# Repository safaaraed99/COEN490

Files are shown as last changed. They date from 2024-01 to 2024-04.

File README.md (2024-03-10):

# COEN490 Hardware
This repository contains the PCB design files and AVR microcontroller firmware.

# Firmware contribution
First, install [Microchip Studio](https://www.microchip.com/en-us/tools-resources/develop/microchip-studio) (AKA Atmel Studio).

Next, create a new branch for the feature you want to add. Open up the solution under avr_firmware, make the modifications, commit and push to your branch. Then open up a PR and wait for a review before merging.

See `docs/main.md` for documentation links and programming guides.

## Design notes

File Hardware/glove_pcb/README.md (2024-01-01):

Hardware design for the project's PCB

1. Download [Kicad](https://www.kicad.org/) and open `glove_pcb.kicad_pro`
2. Modify schematic in `glove_pcb.kicad_sch`
3. Modify PCB layout in `glove_pcb.kicad_pcb`

TODO write more here!!

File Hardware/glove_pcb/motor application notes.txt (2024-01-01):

I_PROPI (uA) = (I_LS1 + I_LS2) (A) * A_IPROPI (uA/A)
    - I_PROPI = Current coming out of IPROPI pin
    - I_LSx = Value in low side MOSFETs of H-bridge
    - A_IPROPI = Current sensing gain (typically 1k uA/A)

V_IPROPI (V) = I_PROPI (uA) * R_IPROPI (Ohm)
    - V_IPROPI = Value measured in ADC, voltage across R_IPROPI
    - R_IPROPI = Resistance between IPROPI pin and ground

I_TRIP (A) * A_IPROPI (uA/A) = V_VREF (V) / R_IPROPI (Ohm)
    - I_TRIP = Max current allowed by current regulator
    - V_VREF = Voltage on VREF input pin (max 3.6V)
    - Note that RHS = I_PROPI
    - Disable current regulation without disabling current regulation by setting V_VREF and R_IPROPI s.t. I_TRIP is never reached

Calculations:
Use maximum recommended V_VREF value of 3.6 V (pin maxes out at 5V but this is recommended max for continuous operation)
Choose I_TRIP = 1A (motor rated for ~0.6A and stalls at ~1.7A)
R_IPROPI = 3.6 kOhm
Gives maximum V_IPROPI of 3.6 V

Alternative I_TRIP = 0.8A
R_IPROPI = 4.5 kOhm
V_IPROPI = 3.6V

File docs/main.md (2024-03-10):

# Hardware Programming Cookbook

## Introduction
This document contains information that will help with programming the ATMega328PB microprocessor used in the project hardware.

## ATMega328PB Pin Assignment and Peripherals
ATMega328PB pinout

* UART 0: Communication with Bluetooth module.
* UART 1: Debug serial communication. Shares pins with SPI 0.
* SPI 0: ISCP. Shares pins with UART 1.
* SPI 1: Communication with ADCs and IMU.
* I2C 0: Not used.
* I2C 1: Not used.
* Hardware timer 0: Both channels used for motor PWM control.
* Hardware timer 1: Both channels used for motor PWM control.
* Hardware timer 2: Channel B used for motor PWM control. Channel A unused.
* Hardware timer 3: Not used.
* Hardware timer 4: Not used.

| Pin identifier | Pin assignment |
| --- | --- |
| PB0 | Peripheral sleep/reset (GPIO) |
| PB1 | Timer/counter 1 output channel A (PWM) |
| PB2 | Timer/counter 1 output channel B (PWM) |
| PB3 | SPI 0 MISO; UART 1 TX |
| PB4 | SPI 0 MOSI; UART 1 RX |
| PB5 | SPI 0 SCK |
| PB6 | Motor 1 fault (GPIO interrupt) |
| PB7 | Motor 2 fault (GPIO interrupt) |
| PC0 | SPI 1 MISO |
| PC1 | SPI 1 SCK |
| PC2 | ADC 2 chip select (GPIO active-low) |
| PC3 | ADC 3 chip select (GPIO active-low) |
| PC4 | Motor phase control 2 (GPIO) |
| PC5 | IMU chip select (GPIO active-low) |
| PC6 | Reset input (GPIO active-low, external pull-up) |
| PD0 | UART 0 RX |
| PD1 | UART 0 TX |
| PD2 | Motor phase control 1 (GPIO) |
| PD3 | Timer/counter 2 output channel B (PWM) |
| PD4 | Motor 5 fault (GPIO interrupt) |
| PD5 | Timer/counter 0 output channel B (PWM) |
| PD6 | Timer/counter 0 output channel A (PWM) |
| PD7 | Motor phase control 3 (GPIO) |
| PE0 | Motor 3 fault (GPIO interrupt) |
| PE1 | Motor 4 fault (GPIO interrupt) |
| PE2 | ADC 1 chip select (GPIO active-low) |
| PE3 | SPI 1 MOSI |

### SPI pin names
* MOSI = Master Out Slave In
* MISO = Master In Slave Out
* SS/CS = Slave Select/Chip Select

All SPI devices share the same MOSI/MISO pins.
Each slave device has a unique CS pin.
CS pins are **ACTIVE-LOW**.
They must be kept high when idle, and should be pulled low by the master (our microcontroller) when we want to communicate with the slave.
Only one CS pin should be low at a time.

## ATMega328PB Programming Guide
[Datasheet](https://ww1.microchip.com/downloads/aemDocuments/documents/MCU08/ProductDocuments/DataSheets/40001906C.pdf)

## ADC Usage Guide
[Datasheet](https://ww1.microchip.com/downloads/en/DeviceDoc/21295d.pdf)

[Useful guide] (https://engineerworkshop.com/blog/interfacing-an-8-bit-microcontroller-with-a-10-bit-device-over-the-spi-protocol/)

## Motor Driver Usage Guide
[Datasheet](https://www.ti.com/lit/ds/symlink/drv8876.pdf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)

## IMU Usage Guide

## Bluetooth Usage Guide
[Datasheet](https://ww1.microchip.com/downloads/en/DeviceDoc/BM70-71-Bluetooth-Low-Energy-BLE-Module-Data-Sheet-DS60001372J.pdf)

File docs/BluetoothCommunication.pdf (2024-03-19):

Bluetooth Communication Protocol
1. Pick UUID Glove:
i. Online generator: 837ee2f0-d412-4af9-b847-c5ffd223640f
2. Control commands (from app to glove)
i. Used by the Android app to send commands to the glove, like starting an exercise or setting resistance.
3. Response commands (from glove to app)
i. Used by the glove to send data back to the app, like sensor readings.
ii. | We need sensor data + ACK.
iii. | Warnings:
i. To send warnings to the glove. The app will show a dialog about the
| warning type and the glove will be set to Stop exercise.
| ii. Glove send 2 bytes (1 byte for warning and the other for the type of
| warning)
| iii. 0x01: Motor Failure
| iv. 0x02: if needed we can add a second warning
v. 0x04: if needed we can add a third warning
4. Communication flow:
i. From Android to Glove: The app writes a command to the Control. For
| example, to set the resistance to level 3, it writes opcode for setting
| resistance.
ii. | From Glove to Android: The glove notifies the Android app via the Response
| with sensor data or acknowledgments. If sending a sensor value of 120, it
| might notify with 0x81, <value>.
Example:
1. Setting Resistance:
a. Android writes 0x0205 to Control Commands to set resistance to level 5.
2. Android App Sends Command to Start Exercise:
a. Writes to Control Commands: EX: 0x01 (start command).
3. Glove Acknowledges and Starts Exercise:
a. writes 0x82 (ACK) to Acknowledge.
b. Begins the exercise.
4. Glove Sends Sensor Data:
a. Glove notifies the Response Commands with 0x81<sensor_value>
| periodically, allowing the Android app to track the user's performance.

Opcodes

Empty | Empty | C | S | W | EMPTY | EMPTY | SR | ST | SE

SE: 0: power down mode, 1: start exercise (if connected 001000 0001 -> 0x81)
ST: 0: power down mode - no effect, 1: stop exercise (if connected 001000 0010 -> 0x82) SR: 0: power down mode, 1: setting resistance + value (10 bits) = 2 bytes for SR (001000 0101 -> 0x85, value (0xvalue)
S: 0: power mode down, 1: searching for Bluetooth devices (000100 0000 -> 0x40)
W: 0: no warning detected, 1: warning is detected (001010 0001, 0xA1), (0xvalue)
C: 1 connected device (if connected, 0x80)
Default value: 001000 0000 iff connected (0x80)

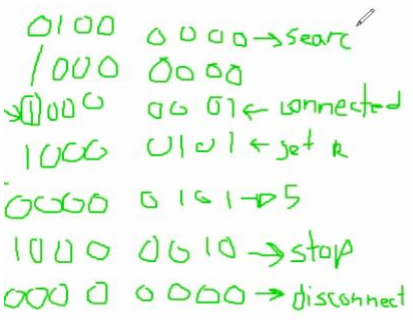
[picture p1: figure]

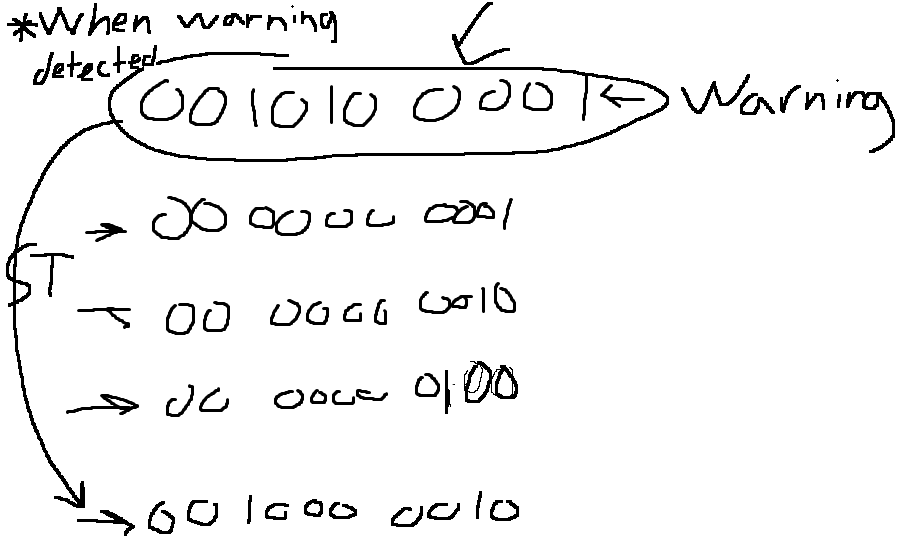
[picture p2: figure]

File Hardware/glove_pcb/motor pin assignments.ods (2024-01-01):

Motor # | Finger | EN (PWM) | PH (GPIO) | FAULT | SLEEP | PMODE
1 | Thumb | OC0A | PD2 | PB6 | PB0 | PD7
2 | Index | OC0B | PD2 | PB7 | PB0 | PD7
3 | Middle | OC1A | PC4 | PE1 | PB0 | PD7
4 | Ring | OC1B | PC4 | PE0 | PB0 | PD7
5 | Pinky | OC2B | PC4 | PD4 | PB0 | PD7
PB0 |  | *OC2A not used, pin is shared with UART1
PD7
PB6
PB7
PE1
PE0
PD4
PD2
PC5
PC4

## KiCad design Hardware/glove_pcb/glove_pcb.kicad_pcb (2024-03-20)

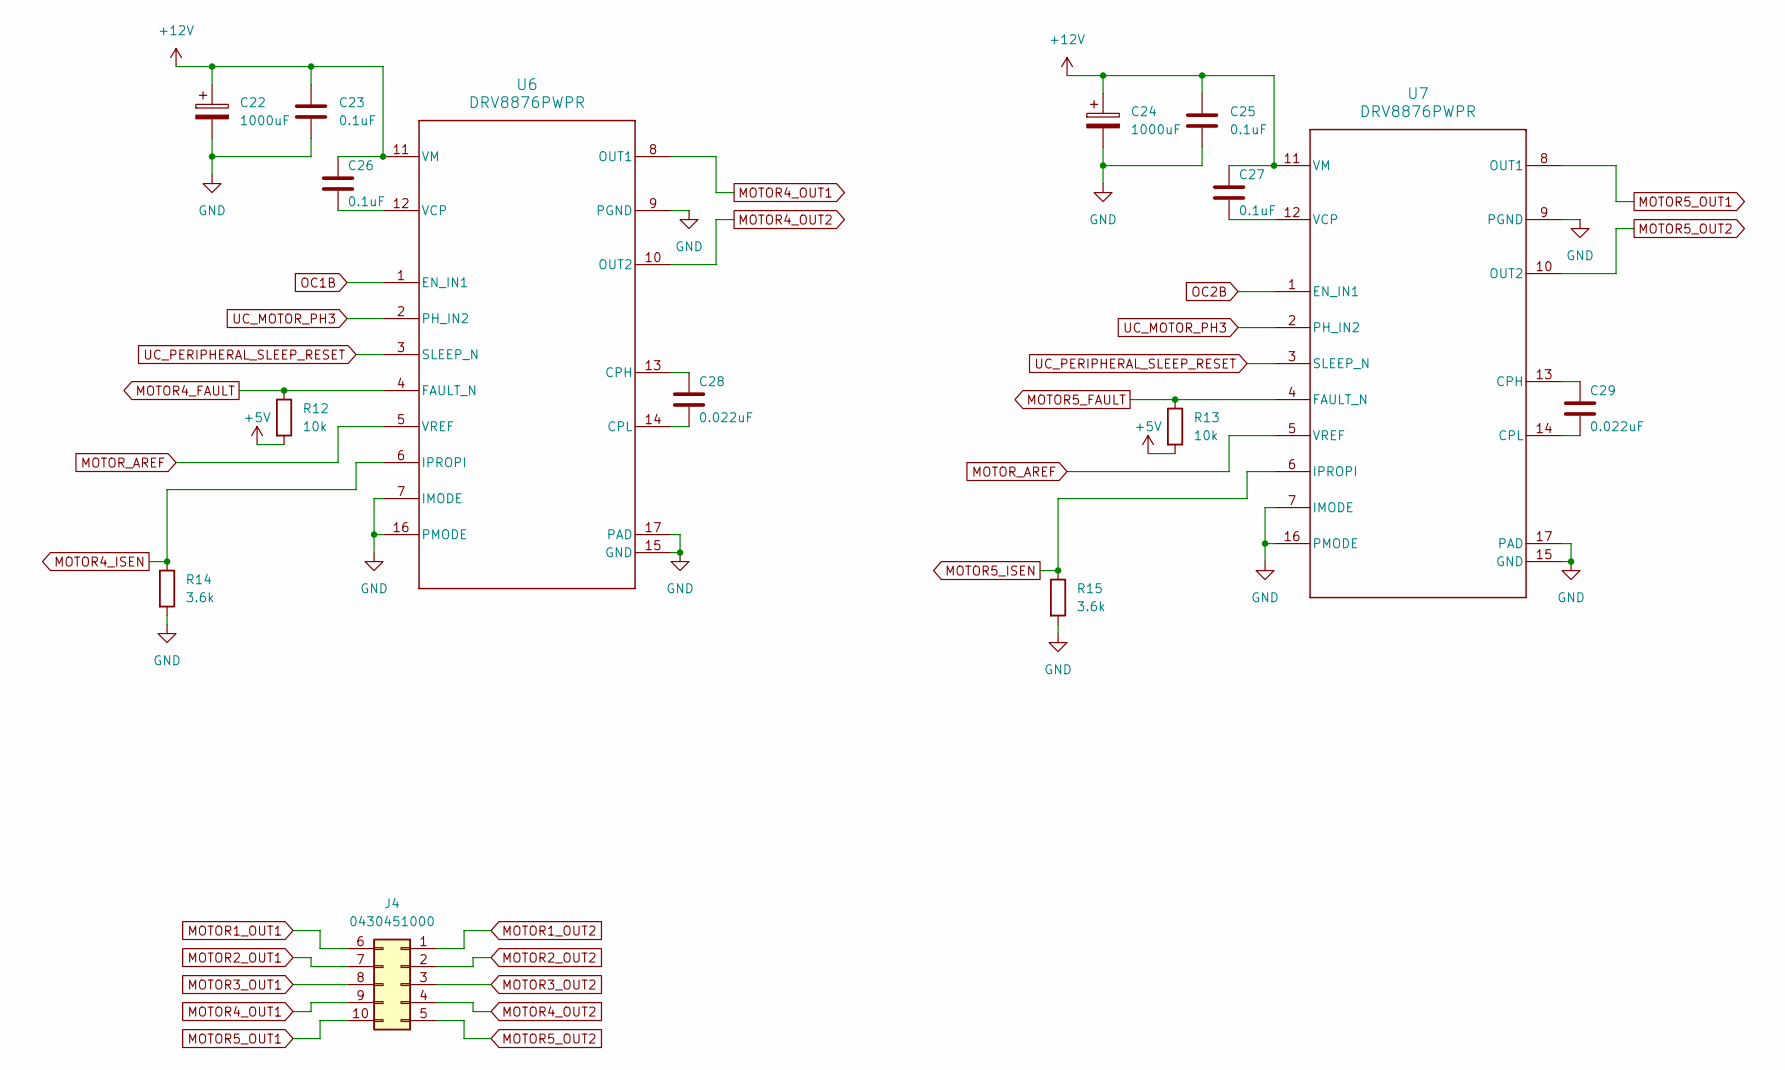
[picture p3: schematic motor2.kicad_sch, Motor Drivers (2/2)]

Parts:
C22, C24: 1000uF; CP_Radial_D10.0mm_P5.00mm
C23, C25, C26, C27: 0.1uF; C_0603_1608Metric_Pad1.08x0.95mm_HandSolder
C28, C29: 0.022uF; C_0603_1608Metric_Pad1.08x0.95mm_HandSolder
J4: 0430451000; Molex_Micro-Fit_3.0_43045-1000_2x05_P3.00mm_Horizontal
R12, R13: 10k; R_0805_2012Metric_Pad1.20x1.40mm_HandSolder
R14, R15: 3.6k; R_0805_2012Metric_Pad1.20x1.40mm_HandSolder
U6, U7: DRV8876PWPR; PWP0016J_N

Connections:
+5V: R12.2, R13.2; also elsewhere on the board
+12V: C22.1, C23.1, C24.1, C25.1, C26.1, C27.1, U6.11 (VM), U7.11 (VM); also elsewhere on the board
GND: C22.2, C23.2, C24.2, C25.2, R14.2, R15.2, U6.7 (IMODE), U6.9 (PGND), U6.15 (GND), U6.16 (PMODE), U6.17 (PAD), U7.7 (IMODE), U7.9 (PGND), U7.15 (GND), U7.16 (PMODE), U7.17 (PAD); also elsewhere on the board
MOTOR1_OUT1: J4.6; also elsewhere on the board
MOTOR1_OUT2: J4.1; also elsewhere on the board
MOTOR2_OUT1: J4.7; also elsewhere on the board
MOTOR2_OUT2: J4.2; also elsewhere on the board
MOTOR3_OUT1: J4.8; also elsewhere on the board
MOTOR3_OUT2: J4.3; also elsewhere on the board
MOTOR4_FAULT: R12.1, U6.4 (FAULT_N); also elsewhere on the board
MOTOR4_ISEN: R14.1, U6.6 (IPROPI); also elsewhere on the board
MOTOR4_OUT1: J4.9, U6.8 (OUT1)
MOTOR4_OUT2: J4.4, U6.10 (OUT2)
MOTOR5_FAULT: R13.1, U7.4 (FAULT_N); also elsewhere on the board
MOTOR5_ISEN: R15.1, U7.6 (IPROPI); also elsewhere on the board
MOTOR5_OUT1: J4.10, U7.8 (OUT1)
MOTOR5_OUT2: J4.5, U7.10 (OUT2)
MOTOR_AREF: U6.5 (VREF), U7.5 (VREF); also elsewhere on the board
unnamed: C28.1, U6.13 (CPH)
unnamed: C28.2, U6.14 (CPL)
unnamed: C26.2, U6.12 (VCP)
unnamed: C29.1, U7.13 (CPH)
unnamed: C29.2, U7.14 (CPL)
unnamed: C27.2, U7.12 (VCP)
OC1B: U6.1 (EN_IN1); also elsewhere on the board
OC2B: U7.1 (EN_IN1); also elsewhere on the board
UC_MOTOR_PH3: U6.2 (PH_IN2), U7.2 (PH_IN2); also elsewhere on the board
UC_PERIPHERAL_SLEEP_RESET: U6.3 (SLEEP_N), U7.3 (SLEEP_N); also elsewhere on the board

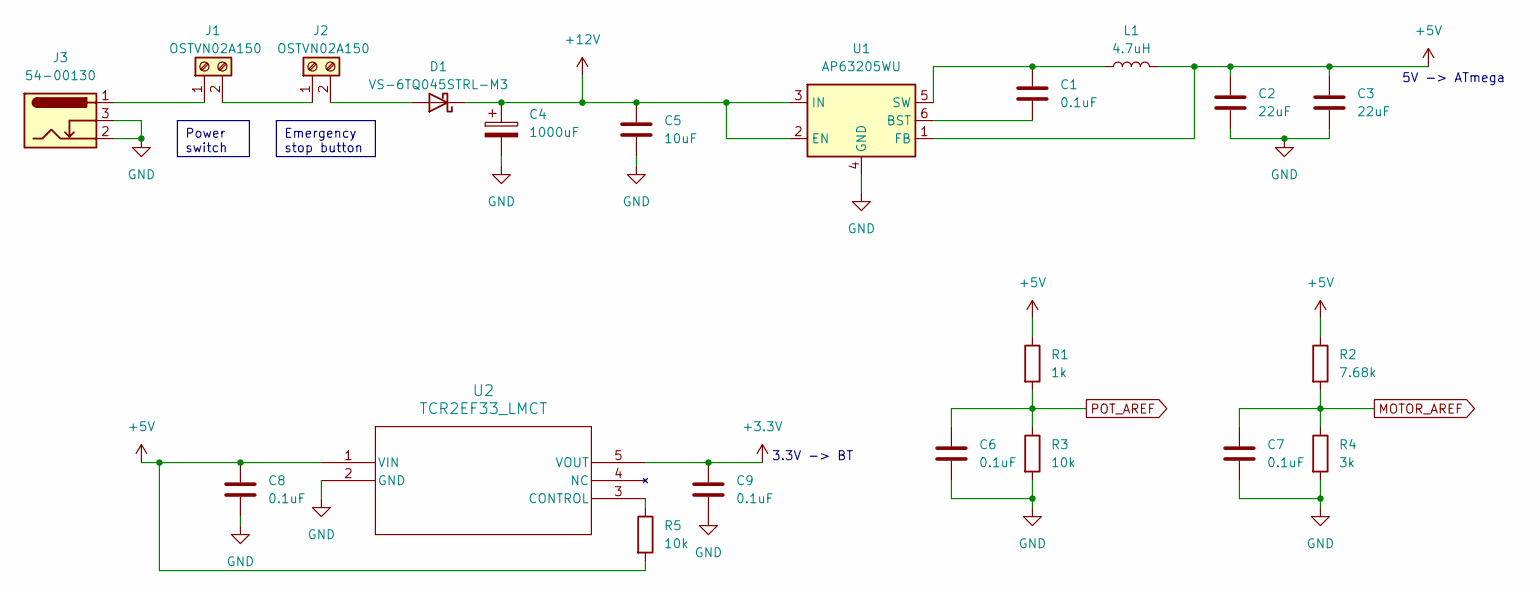
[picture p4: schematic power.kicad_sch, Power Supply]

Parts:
C1, C6, C7, C8, C9: 0.1uF; C_0603_1608Metric_Pad1.08x0.95mm_HandSolder
C2, C3: 22uF; C_0805_2012Metric_Pad1.18x1.45mm_HandSolder
C4: 1000uF; CP_Radial_D10.0mm_P5.00mm
C5: 10uF; C_1206_3216Metric_Pad1.33x1.80mm_HandSolder
D1: VS-6TQ045STRL-M3; TO-263-3_TabPin2
J1, J2: OSTVN02A150; TerminalBlock_OnShore_OSTVN02A150_P2.54mm
J3: 54-00130; BarrelJack_Horizontal
L1: 4.7uH; L_7.6x7.6_H3.5
R1: 1k; R_0805_2012Metric_Pad1.20x1.40mm_HandSolder
R2: 7.68k; R_1206_3216Metric_Pad1.30x1.75mm_HandSolder
R3, R5: 10k; R_0805_2012Metric_Pad1.20x1.40mm_HandSolder
R4: 3k; R_0805_2012Metric_Pad1.20x1.40mm_HandSolder
U1: AP63205WU; TSOT-23-6
U2: TCR2EF33_LMCT; SOT-25 SMV_TOS

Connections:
+3.3V: C9.1, U2.5 (VOUT); also elsewhere on the board
+5V: C2.1, C3.1, C8.1, L1.2, R1.1, R2.1, R5.2, U1.1 (FB), U2.1 (VIN); also elsewhere on the board
+12V: C4.1, C5.1, D1.2 (K), U1.2 (EN), U1.3 (IN); also elsewhere on the board
GND: C2.2, C3.2, C4.2, C5.2, C6.2, C7.2, C8.2, C9.2, J3.2, J3.3, R3.2, R4.2, U1.4 (GND), U2.2 (GND); also elsewhere on the board
MOTOR_AREF: C7.1, R2.2, R4.1; also elsewhere on the board
unnamed: D1.3 (A), J2.2
unnamed: J1.1, J3.1
unnamed: J1.2, J2.1
unnamed: C1.2, U1.6 (BST)
unnamed: C1.1, L1.1, U1.5 (SW)
unnamed: R5.1, U2.3 (CONTROL)
POT_AREF: C6.1, R1.2, R3.1; also elsewhere on the board

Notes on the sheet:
Power switch
Emergency stop button
5V -> ATmega
3.3V -> BT

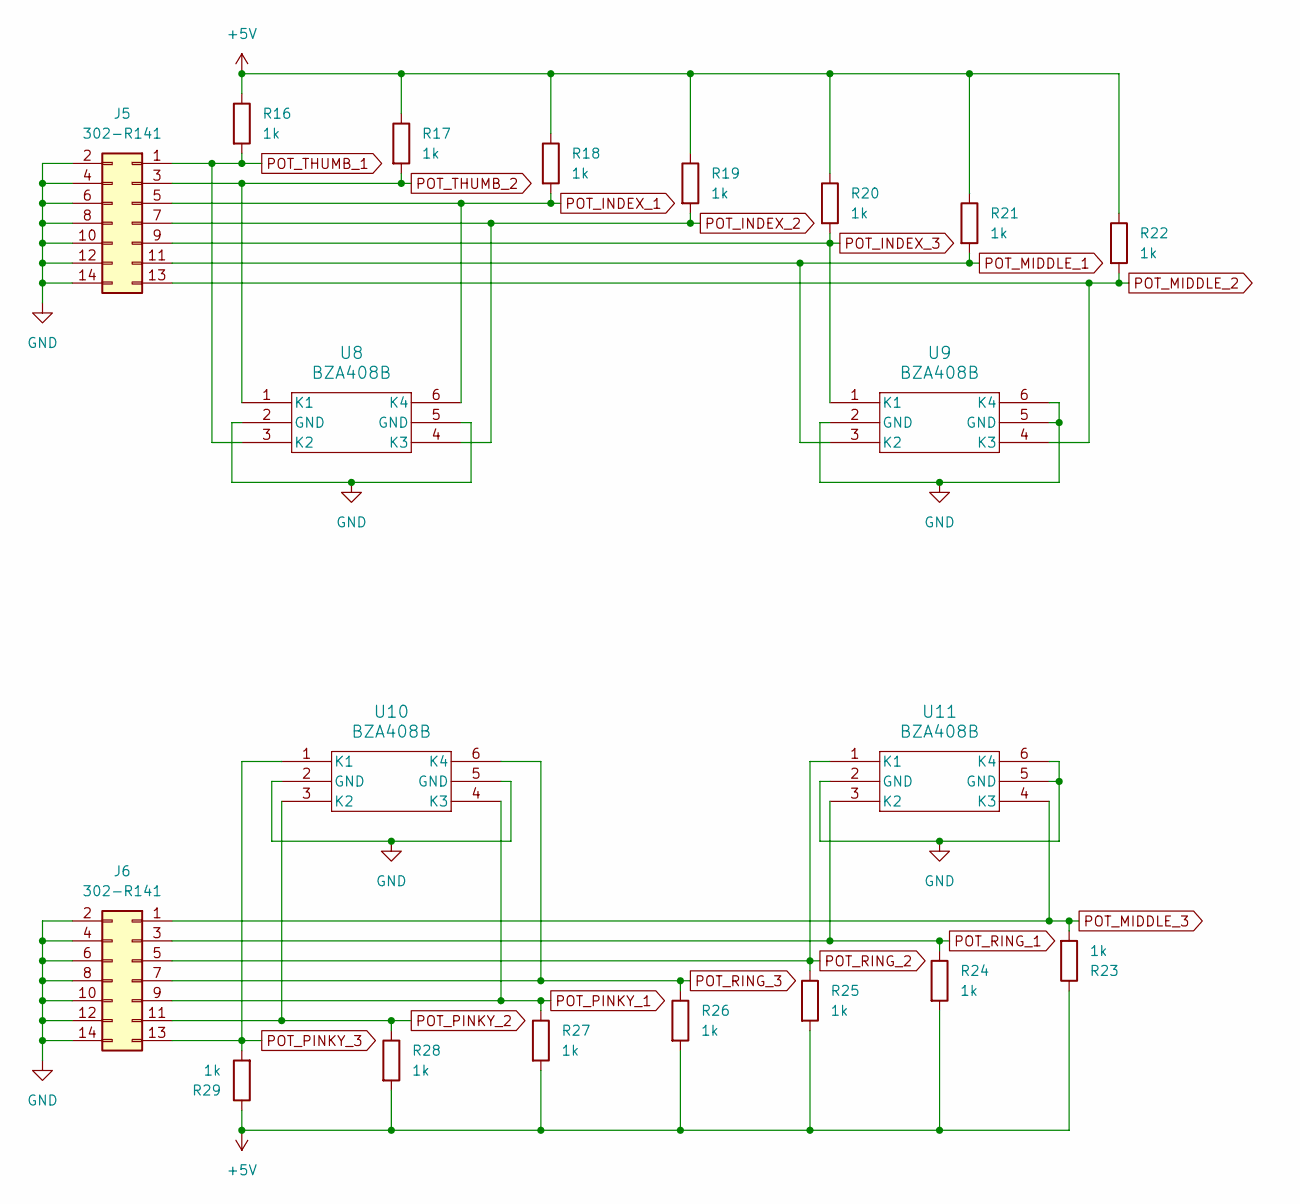
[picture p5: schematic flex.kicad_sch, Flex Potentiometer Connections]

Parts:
J5, J6: 302-R141; PinSocket_2x07_P2.54mm_Horizontal_302-R141
R16, R17, R18, R19, R20, R21, R22, R23, R24, R25, R26, R27, R28, R29: 1k; R_0805_2012Metric_Pad1.20x1.40mm_HandSolder
U8, U9, U10, U11: BZA408B; SOT457_NXP

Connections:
+5V: R16.1, R17.1, R18.1, R19.1, R20.1, R21.1, R22.1, R23.1, R24.2, R25.2, R26.2, R27.2, R28.2, R29.1; also elsewhere on the board
GND: J5.2, J5.4, J5.6, J5.8, J5.10, J5.12, J5.14, J6.2, J6.4, J6.6, J6.8, J6.10, J6.12, J6.14, U8.2 (GND), U8.5 (GND), U9.2 (GND), U9.5 (GND), U9.6 (K4), U10.2 (GND), U10.5 (GND), U11.2 (GND), U11.5 (GND), U11.6 (K4); also elsewhere on the board
POT_INDEX_1: J5.5, R18.2, U8.6 (K4); also elsewhere on the board
POT_INDEX_2: J5.7, R19.2, U8.4 (K3); also elsewhere on the board
POT_INDEX_3: J5.9, R20.2, U9.1 (K1); also elsewhere on the board
POT_MIDDLE_1: J5.11, R21.2, U9.3 (K2); also elsewhere on the board
POT_MIDDLE_2: J5.13, R22.2, U9.4 (K3); also elsewhere on the board
POT_MIDDLE_3: J6.1, R23.2, U11.4 (K3); also elsewhere on the board
POT_PINKY_1: J6.9, R27.1, U10.4 (K3); also elsewhere on the board
POT_PINKY_2: J6.11, R28.1, U10.3 (K2); also elsewhere on the board
POT_PINKY_3: J6.13, R29.2, U10.1 (K1); also elsewhere on the board
POT_RING_1: J6.3, R24.1, U11.3 (K2); also elsewhere on the board
POT_RING_2: J6.5, R25.1, U11.1 (K1); also elsewhere on the board
POT_RING_3: J6.7, R26.1, U10.6 (K4); also elsewhere on the board
POT_THUMB_1: J5.1, R16.2, U8.3 (K2); also elsewhere on the board
POT_THUMB_2: J5.3, R17.2, U8.1 (K1); also elsewhere on the board

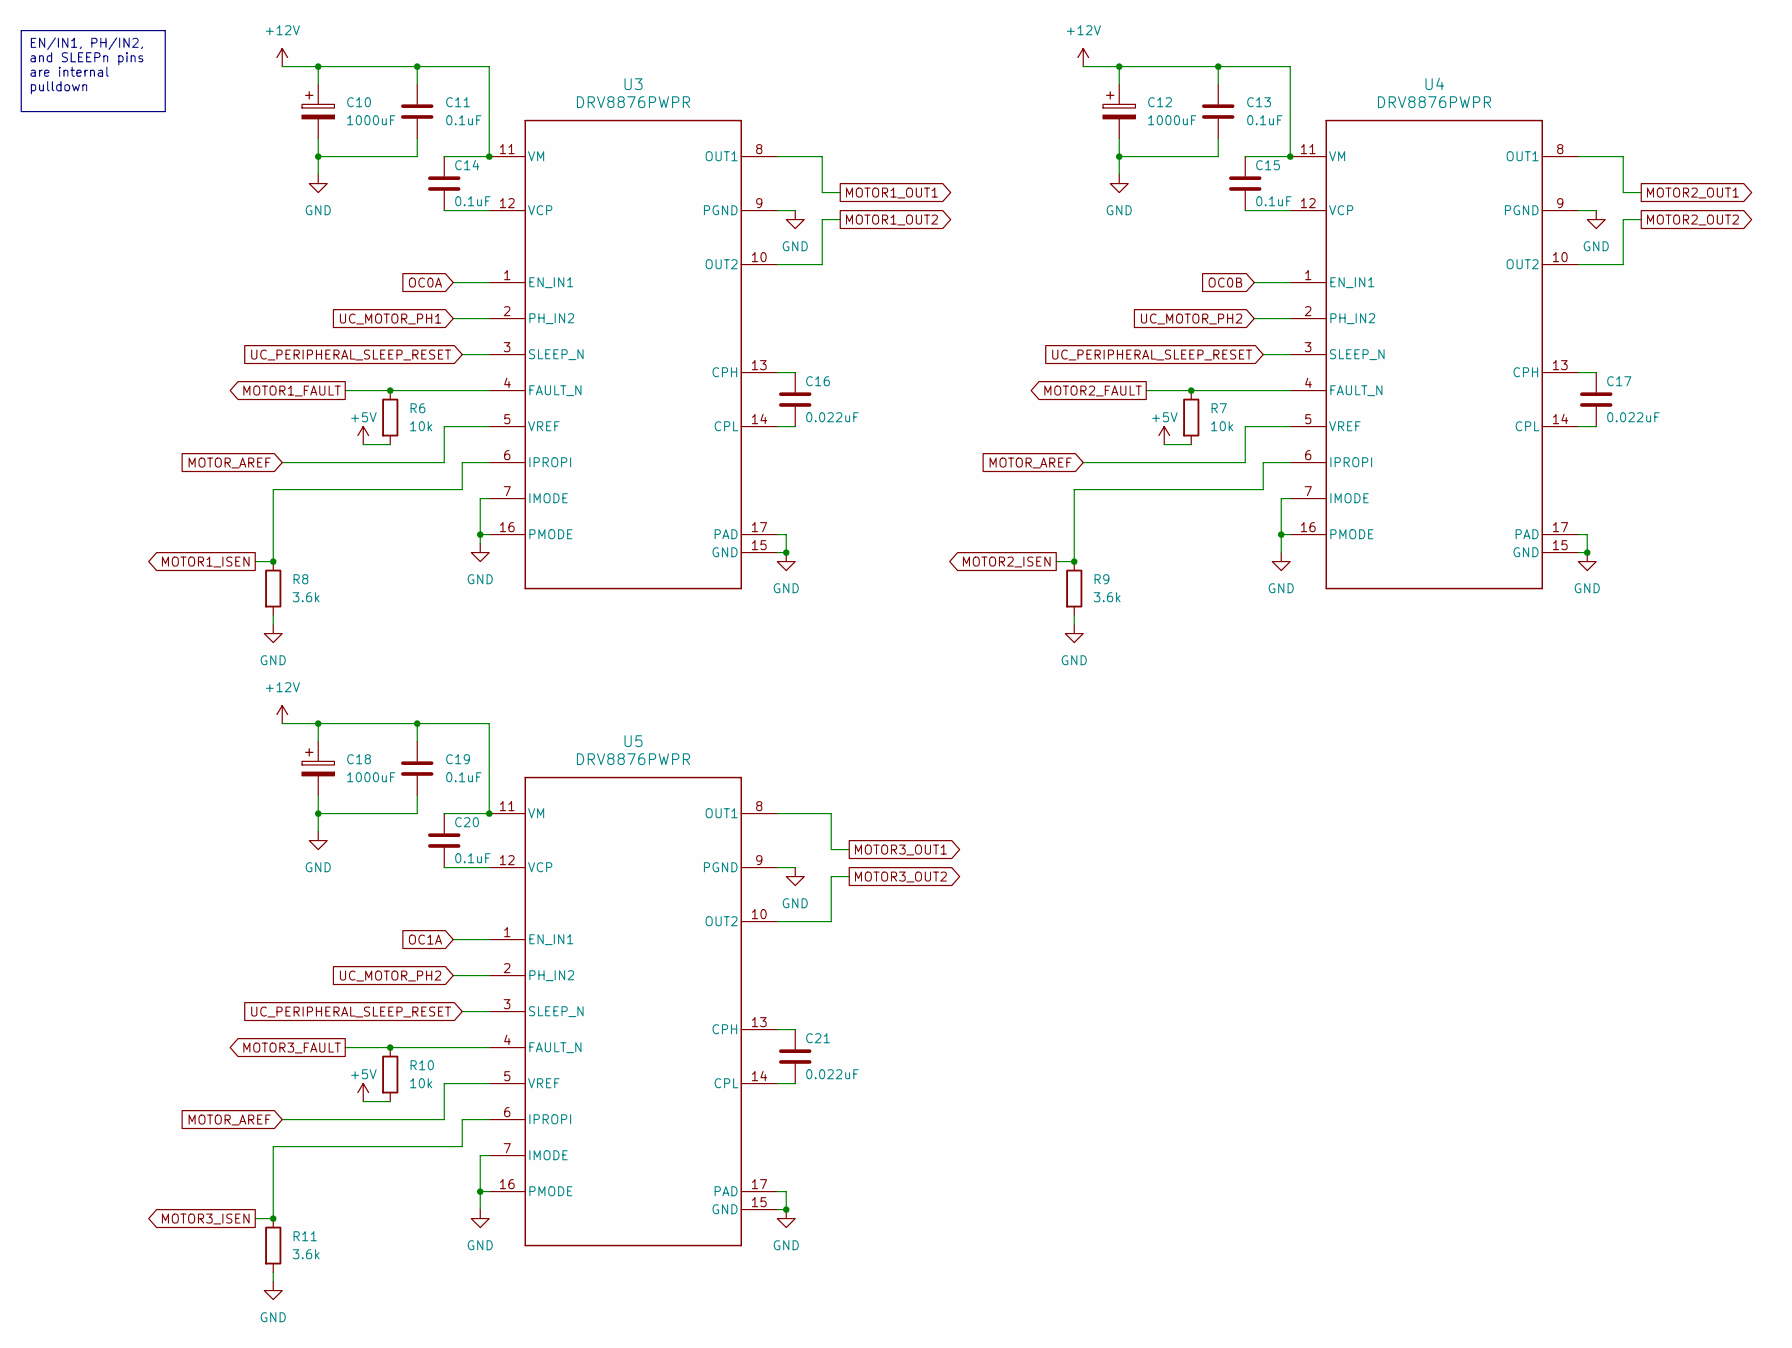
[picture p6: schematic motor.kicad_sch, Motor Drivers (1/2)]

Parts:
C10, C12, C18: 1000uF; CP_Radial_D10.0mm_P5.00mm
C11, C13, C14, C15, C19, C20: 0.1uF; C_0603_1608Metric_Pad1.08x0.95mm_HandSolder
C16, C17, C21: 0.022uF; C_0603_1608Metric_Pad1.08x0.95mm_HandSolder
R6, R7, R10: 10k; R_0805_2012Metric_Pad1.20x1.40mm_HandSolder
R8, R9, R11: 3.6k; R_0805_2012Metric_Pad1.20x1.40mm_HandSolder
U3, U4, U5: DRV8876PWPR; PWP0016J_N

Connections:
+5V: R6.2, R7.2, R10.2; also elsewhere on the board
+12V: C10.1, C11.1, C12.1, C13.1, C14.1, C15.1, C18.1, C19.1, C20.1, U3.11 (VM), U4.11 (VM), U5.11 (VM); also elsewhere on the board
GND: C10.2, C11.2, C12.2, C13.2, C18.2, C19.2, R8.2, R9.2, R11.2, U3.7 (IMODE), U3.9 (PGND), U3.15 (GND), U3.16 (PMODE), U3.17 (PAD), U4.7 (IMODE), U4.9 (PGND), U4.15 (GND), U4.16 (PMODE), U4.17 (PAD), U5.7 (IMODE), U5.9 (PGND), U5.15 (GND), U5.16 (PMODE), U5.17 (PAD); also elsewhere on the board
MOTOR1_FAULT: R6.1, U3.4 (FAULT_N); also elsewhere on the board
MOTOR1_ISEN: R8.1, U3.6 (IPROPI); also elsewhere on the board
MOTOR1_OUT1: U3.8 (OUT1); also elsewhere on the board
MOTOR1_OUT2: U3.10 (OUT2); also elsewhere on the board
MOTOR2_FAULT: R7.1, U4.4 (FAULT_N); also elsewhere on the board
MOTOR2_ISEN: R9.1, U4.6 (IPROPI); also elsewhere on the board
MOTOR2_OUT1: U4.8 (OUT1); also elsewhere on the board
MOTOR2_OUT2: U4.10 (OUT2); also elsewhere on the board
MOTOR3_FAULT: R10.1, U5.4 (FAULT_N); also elsewhere on the board
MOTOR3_ISEN: R11.1, U5.6 (IPROPI); also elsewhere on the board
MOTOR3_OUT1: U5.8 (OUT1); also elsewhere on the board
MOTOR3_OUT2: U5.10 (OUT2); also elsewhere on the board
MOTOR_AREF: U3.5 (VREF), U4.5 (VREF), U5.5 (VREF); also elsewhere on the board
unnamed: C16.1, U3.13 (CPH)
unnamed: C16.2, U3.14 (CPL)
unnamed: C14.2, U3.12 (VCP)
unnamed: C17.1, U4.13 (CPH)
unnamed: C17.2, U4.14 (CPL)
unnamed: C15.2, U4.12 (VCP)
unnamed: C21.1, U5.13 (CPH)
unnamed: C21.2, U5.14 (CPL)
unnamed: C20.2, U5.12 (VCP)
OC0A: U3.1 (EN_IN1); also elsewhere on the board
OC0B: U4.1 (EN_IN1); also elsewhere on the board
OC1A: U5.1 (EN_IN1); also elsewhere on the board
UC_MOTOR_PH1: U3.2 (PH_IN2); also elsewhere on the board
UC_MOTOR_PH2: U4.2 (PH_IN2), U5.2 (PH_IN2); also elsewhere on the board
UC_PERIPHERAL_SLEEP_RESET: U3.3 (SLEEP_N), U4.3 (SLEEP_N), U5.3 (SLEEP_N); also elsewhere on the board

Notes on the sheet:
EN/IN1, PH/IN2, and SLEEPn pins are internal pulldown

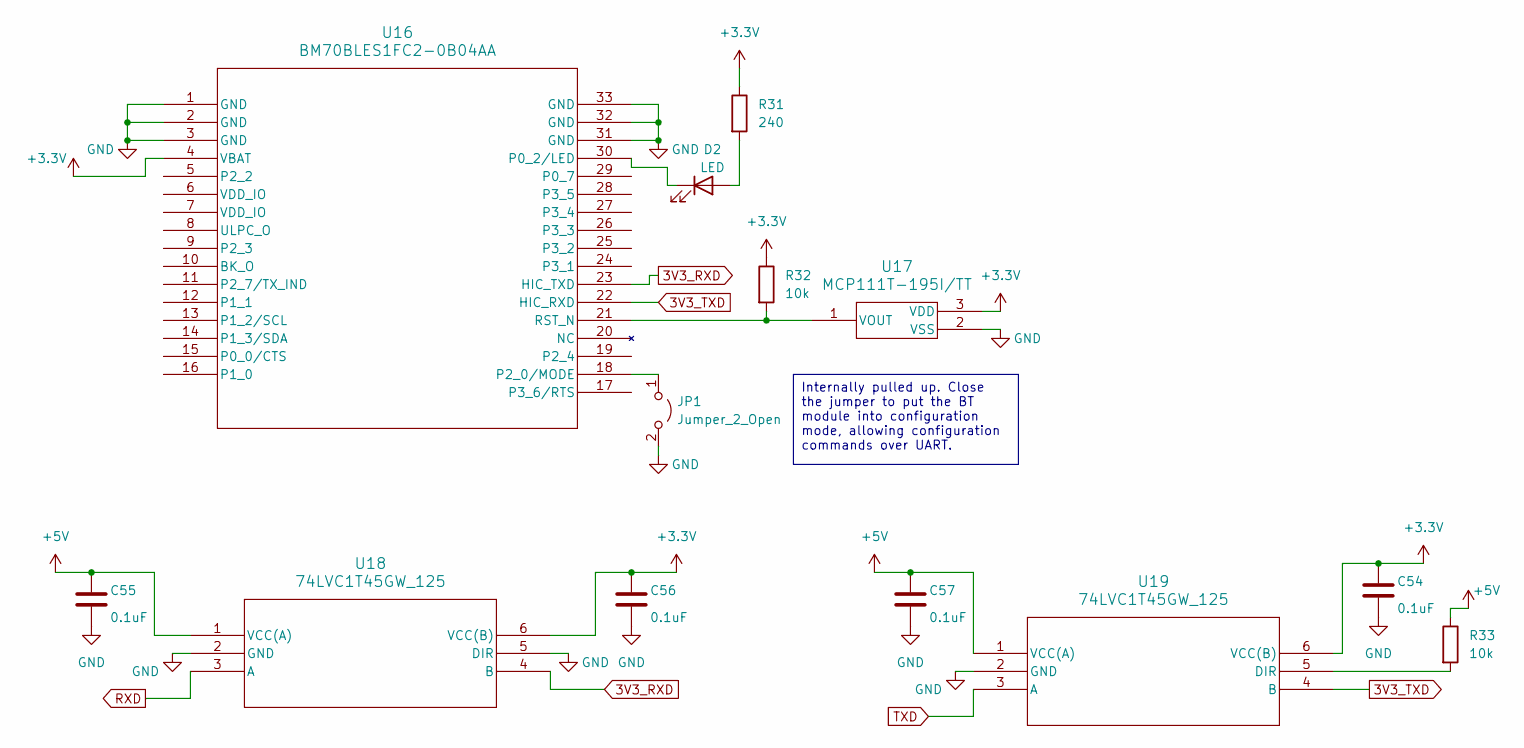
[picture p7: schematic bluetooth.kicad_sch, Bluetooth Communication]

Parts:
C54, C55, C56, C57: 0.1uF; C_0603_1608Metric_Pad1.08x0.95mm_HandSolder
D2: LED; LED_D5.0mm
JP1: Jumper_2_Open; PinHeader_1x02_P2.54mm_Vertical
R31: 240; R_0805_2012Metric_Pad1.20x1.40mm_HandSolder
R32, R33: 10k; R_0805_2012Metric_Pad1.20x1.40mm_HandSolder
U16: BM70BLES1FC2-0B04AA; BM70BLES1FC2_MCH(2)
U17: MCP111T-195I/TT; SOT-23_MC_MCH
U18, U19: 74LVC1T45GW_125; TSSOP6_SOT363-2_NEX

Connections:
3V3_RXD: U16.23 (HIC_TXD), U18.4 (B)
3V3_TXD: U16.22 (HIC_RXD), U19.4 (B)
+3.3V: C54.1, C56.1, R31.1, R32.1, U16.4 (VBAT), U17.3 (VDD), U18.6 (VCC(B)), U19.6 (VCC(B)); also elsewhere on the board
+5V: C55.1, C57.1, R33.1, U18.1 (VCC(A)), U19.1 (VCC(A)); also elsewhere on the board
GND: C54.2, C55.2, C56.2, C57.2, JP1.2 (B), U16.1 (GND), U16.2 (GND), U16.3 (GND), U16.31 (GND), U16.32 (GND), U16.33 (GND), U17.2 (VSS), U18.2 (GND), U18.5 (DIR), U19.2 (GND); also elsewhere on the board
unnamed: D2.2 (A), R31.2
unnamed: D2.1 (K), U16.30 (P0_2/LED)
unnamed: JP1.1 (A), U16.18 (P2_0/MODE)
unnamed: R32.2, U16.21 (RST_N), U17.1 (VOUT)
unnamed: R33.2, U19.5 (DIR)
RXD: U18.3 (A); also elsewhere on the board
TXD: U19.3 (A); also elsewhere on the board

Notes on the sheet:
Internally pulled up. Close the jumper to put the BT module into configuration mode, allowing configuration commands over UART.

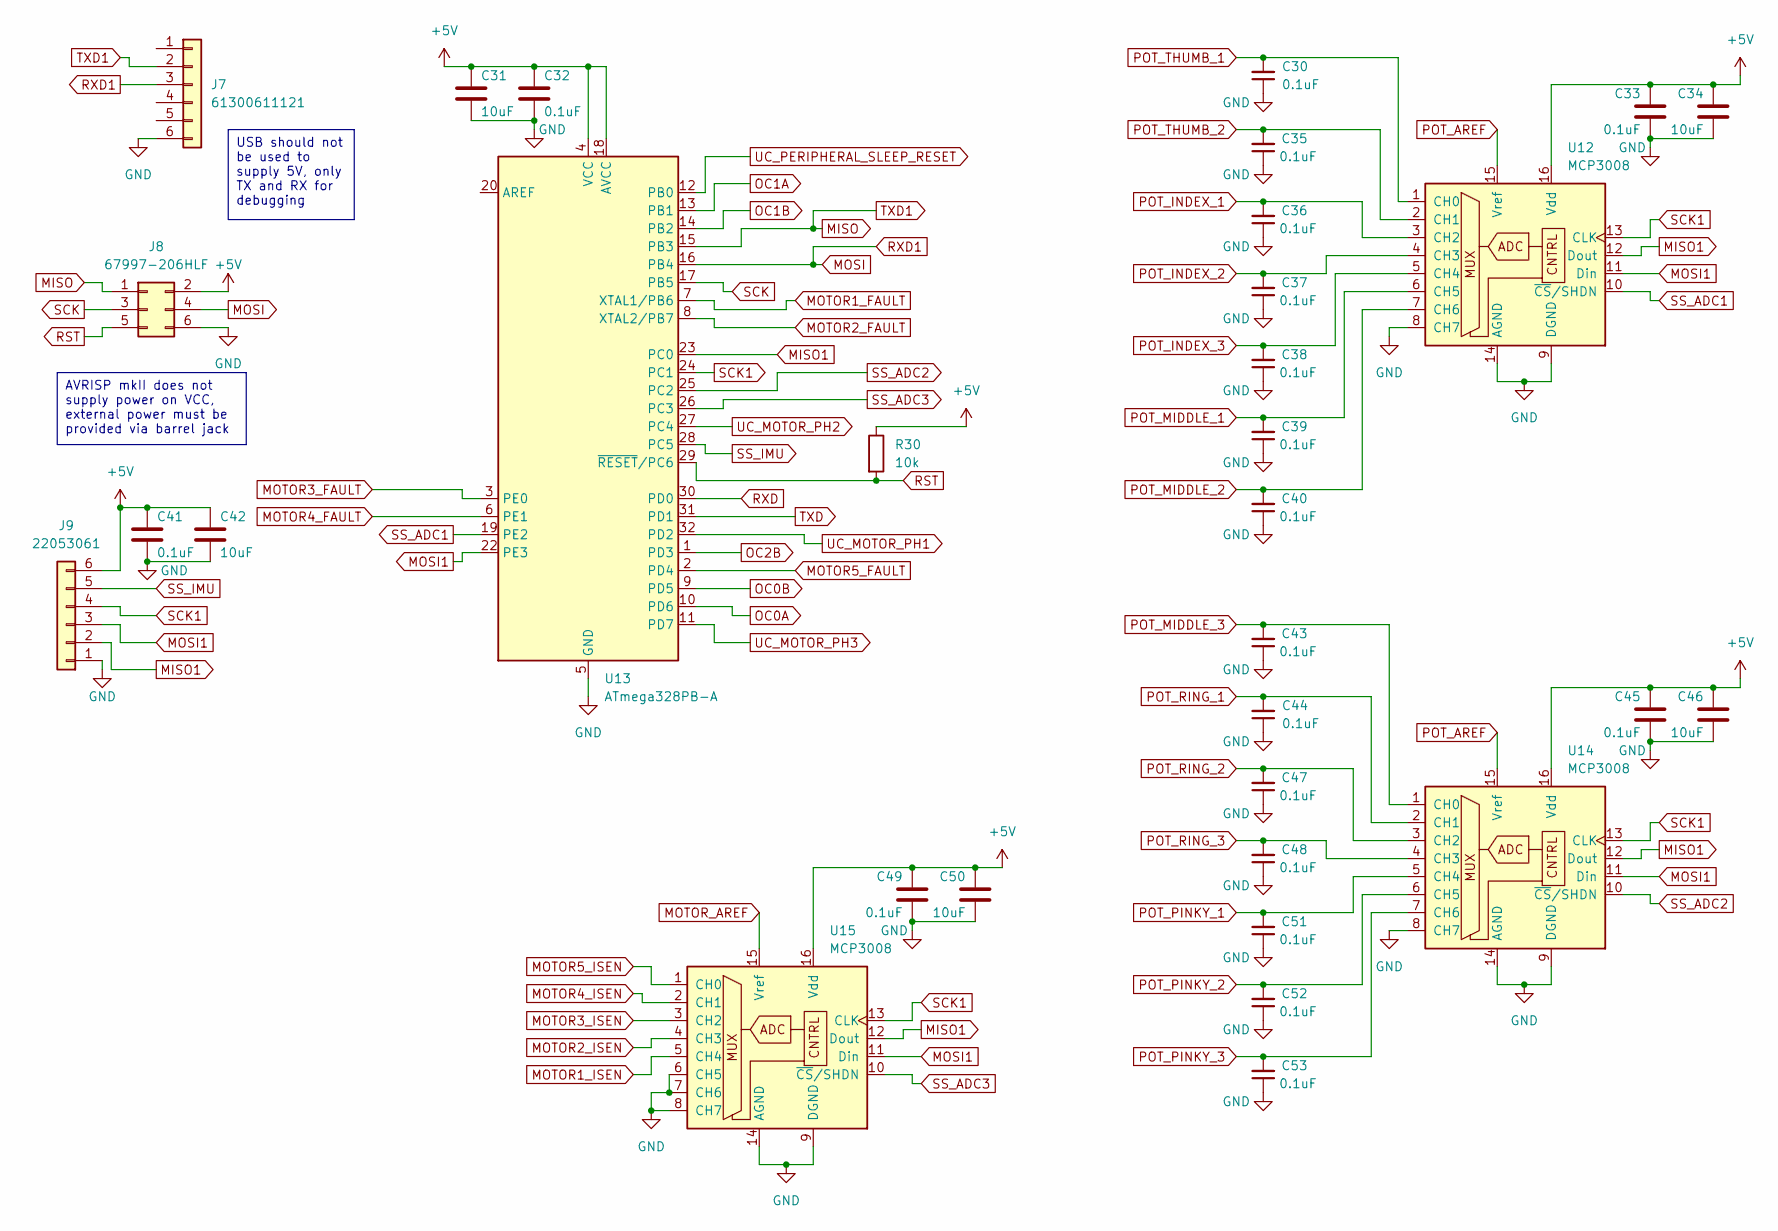
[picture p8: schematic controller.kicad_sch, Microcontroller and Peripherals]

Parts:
C30, C32, C33, C35, C36, C37, C38, C39, C40, C41, C43, C44, C45, C47, C48, C49, C51, C52, C53: 0.1uF; C_0603_1608Metric_Pad1.08x0.95mm_HandSolder
C31, C34, C42, C46, C50: 10uF; C_1206_3216Metric_Pad1.33x1.80mm_HandSolder
J7: 61300611121; PinSocket_1x06_P2.54mm_Vertical
J8: 67997-206HLF; PinHeader_2x03_P2.54mm_Vertical
J9: 22053061; PinSocket_1x06_P2.54mm_Horizontal
R30: 10k; R_0805_2012Metric_Pad1.20x1.40mm_HandSolder
U12, U14, U15: MCP3008; SOIC-16_3.9x9.9mm_P1.27mm
U13: ATmega328PB-A; TQFP-32_7x7mm_P0.8mm

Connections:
+5V: C31.1, C32.1, C33.1, C34.1, C41.1, C42.1, C45.1, C46.1, C49.1, C50.1, J8.2, J9.6, R30.1, U12.16 (Vdd), U13.4 (VCC), U13.18 (AVCC), U14.16 (Vdd), U15.16 (Vdd); also elsewhere on the board
GND: C30.1, C31.2, C32.2, C33.2, C34.2, C35.1, C36.1, C37.1, C38.1, C39.1, C40.1, C41.2, C42.2, C43.1, C44.1, C45.2, C46.2, C47.1, C48.1, C49.2, C50.2, C51.1, C52.1, C53.1, J7.6, J8.6, J9.1, U12.8 (CH7), U12.9 (DGND), U12.14 (AGND), U13.5 (GND), U13.21 (GND), U14.8 (CH7), U14.9 (DGND), U14.14 (AGND), U15.6 (CH5), U15.7 (CH6), U15.8 (CH7), U15.9 (DGND), U15.14 (AGND); also elsewhere on the board
MISO: J7.2, J8.1, U13.15 (PB3)
MISO1: J9.2, U12.12 (Dout), U13.23 (PC0), U14.12 (Dout), U15.12 (Dout)
MOSI: J7.3, J8.4, U13.16 (PB4)
MOSI1: J9.3, U12.11 (Din), U13.22 (PE3), U14.11 (Din), U15.11 (Din)
MOTOR1_FAULT: U13.7 (XTAL1/PB6); also elsewhere on the board
MOTOR1_ISEN: U15.5 (CH4); also elsewhere on the board
MOTOR2_FAULT: U13.8 (XTAL2/PB7); also elsewhere on the board
MOTOR2_ISEN: U15.4 (CH3); also elsewhere on the board
MOTOR3_FAULT: U13.3 (PE0); also elsewhere on the board
MOTOR3_ISEN: U15.3 (CH2); also elsewhere on the board
MOTOR4_FAULT: U13.6 (PE1); also elsewhere on the board
MOTOR4_ISEN: U15.2 (CH1); also elsewhere on the board
MOTOR5_FAULT: U13.2 (PD4); also elsewhere on the board
MOTOR5_ISEN: U15.1 (CH0); also elsewhere on the board
MOTOR_AREF: U15.15 (Vref); also elsewhere on the board
OC0A: U13.10 (PD6); also elsewhere on the board
OC0B: U13.9 (PD5); also elsewhere on the board
OC1A: U13.13 (PB1); also elsewhere on the board
OC1B: U13.14 (PB2); also elsewhere on the board
OC2B: U13.1 (PD3); also elsewhere on the board
POT_AREF: U12.15 (Vref), U14.15 (Vref); also elsewhere on the board
POT_INDEX_1: C36.2, U12.3 (CH2); also elsewhere on the board
POT_INDEX_2: C37.2, U12.4 (CH3); also elsewhere on the board
POT_INDEX_3: C38.2, U12.5 (CH4); also elsewhere on the board
POT_MIDDLE_1: C39.2, U12.6 (CH5); also elsewhere on the board
POT_MIDDLE_2: C40.2, U12.7 (CH6); also elsewhere on the board
POT_MIDDLE_3: C43.2, U14.1 (CH0); also elsewhere on the board
POT_PINKY_1: C51.2, U14.5 (CH4); also elsewhere on the board
POT_PINKY_2: C52.2, U14.6 (CH5); also elsewhere on the board
POT_PINKY_3: C53.2, U14.7 (CH6); also elsewhere on the board
POT_RING_1: C44.2, U14.2 (CH1); also elsewhere on the board
POT_RING_2: C47.2, U14.3 (CH2); also elsewhere on the board
POT_RING_3: C48.2, U14.4 (CH3); also elsewhere on the board
POT_THUMB_1: C30.2, U12.1 (CH0); also elsewhere on the board
POT_THUMB_2: C35.2, U12.2 (CH1); also elsewhere on the board
RST: J8.5, R30.2, U13.29 (~RESET/PC6)
RXD: U13.30 (PD0); also elsewhere on the board
SCK: J8.3, U13.17 (PB5)
SCK1: J9.4, U12.13 (CLK), U13.24 (PC1), U14.13 (CLK), U15.13 (CLK)
SS_ADC1: U12.10 (~CS/SHDN), U13.19 (PE2)
SS_ADC2: U13.25 (PC2), U14.10 (~CS/SHDN)
SS_ADC3: U13.26 (PC3), U15.10 (~CS/SHDN)
SS_IMU: J9.5, U13.28 (PC5)
TXD: U13.31 (PD1); also elsewhere on the board
UC_MOTOR_PH1: U13.32 (PD2); also elsewhere on the board
UC_MOTOR_PH2: U13.27 (PC4); also elsewhere on the board
UC_MOTOR_PH3: U13.11 (PD7); also elsewhere on the board
UC_PERIPHERAL_SLEEP_RESET: U13.12 (PB0); also elsewhere on the board

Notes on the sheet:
USB should not be used to supply 5V, only TX and RX for debugging
AVRISP mkII does not supply power on VCC, external power must be provided via barrel jack

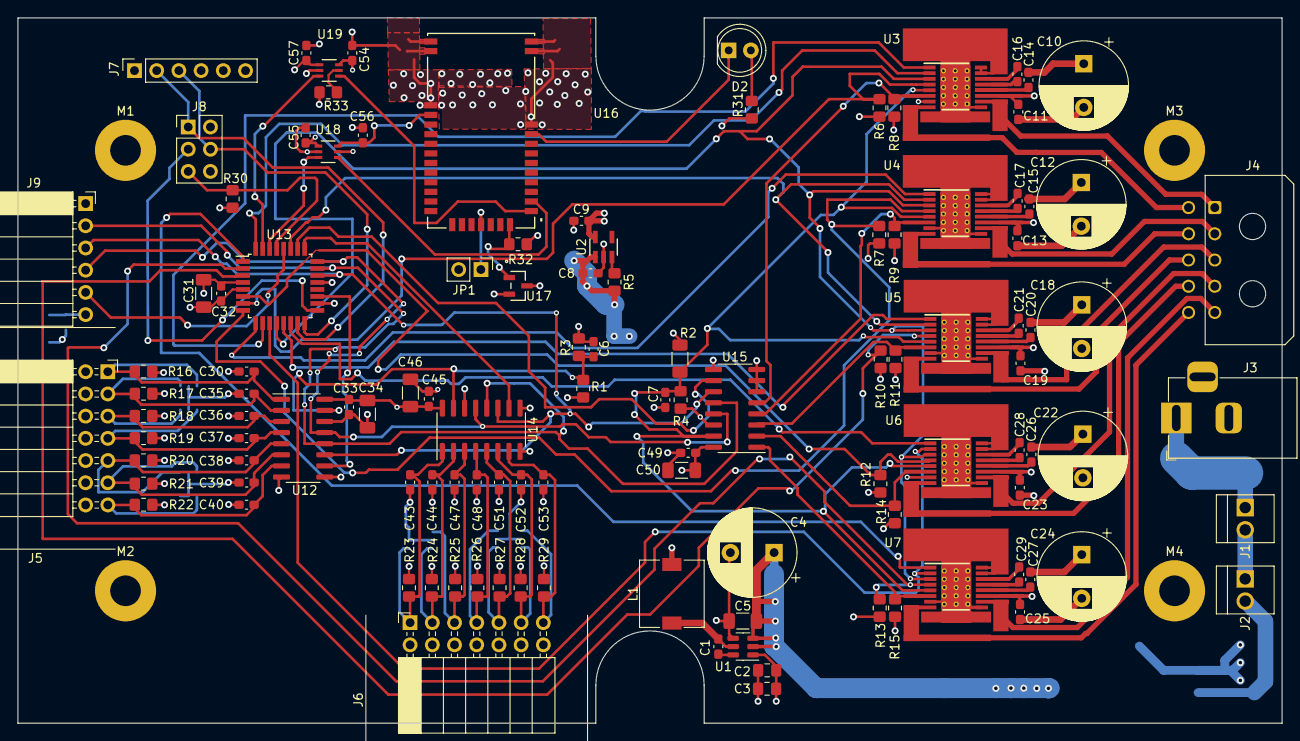
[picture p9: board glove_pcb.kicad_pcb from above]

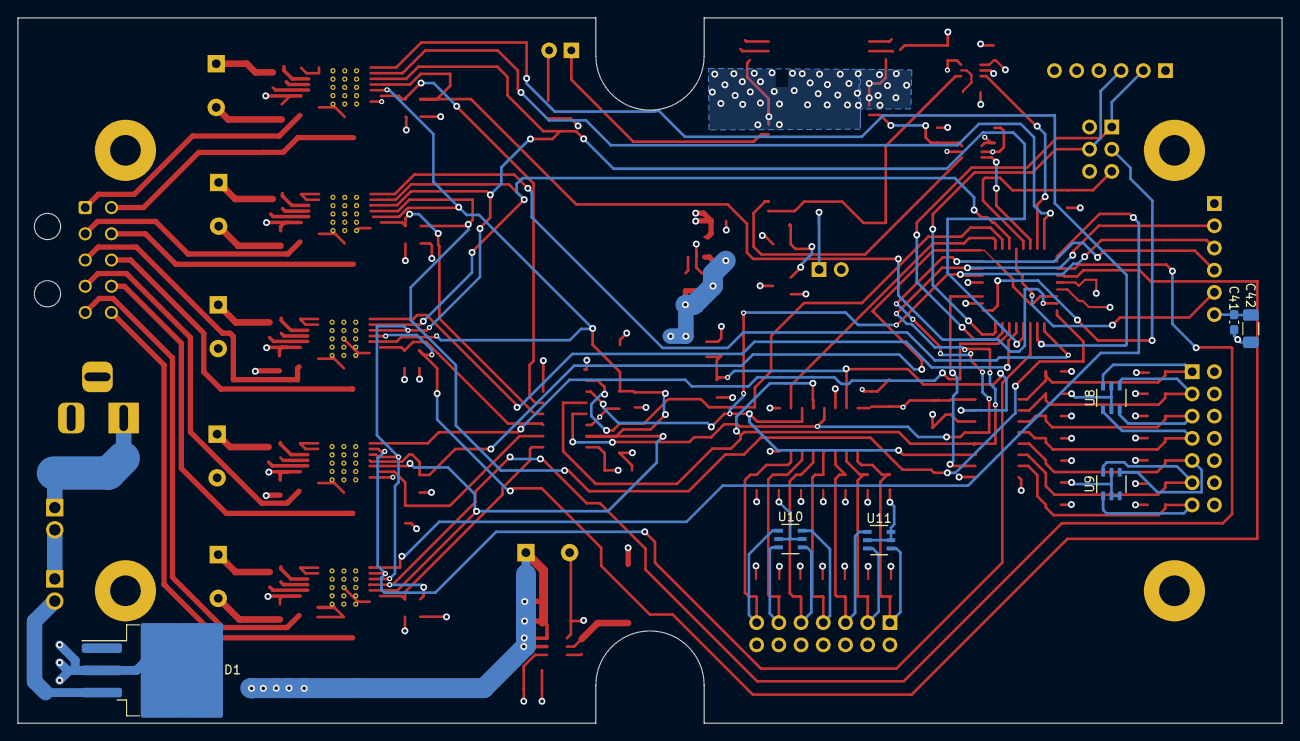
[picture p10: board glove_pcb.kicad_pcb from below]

Board: 4 copper layers, 144.6 x 80.7 mm, 126 parts (7 on the bottom side), 90 nets.

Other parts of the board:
M1, M2, M3, M4: MountingHole_3.5mm_Pad

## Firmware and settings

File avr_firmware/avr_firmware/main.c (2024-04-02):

/*
 * avr_firmware.c
 *
 * Created: 2024-03-10 5:43:47 PM
 * Author : Matthew Faigan
 */ 

#define F_CPU 8000000UL

#include <avr/io.h>
#include <avr/interrupt.h>
#include <string.h>
#include <stdio.h>
#include <stdbool.h>
#include <util/delay.h>

#include "spi.h"
#include "uart.h"
#include "motor.h"

// Number of timer 3 overflows to occur for ~0.5s of real time to pass
#define TC3_OVF_HALF_SECOND 61

extern volatile bool motor_faulted[MOTOR_COUNT];

static volatile int8_t motor_cycles_remaining[MOTOR_COUNT];

void setup_gpio(void);
int8_t check_finger_flexion(adc_readings_t *current, adc_readings_t *prev, potentiometer knuckle1, potentiometer knuckle2, potentiometer knuckle3);

// REAL MAIN
int main(void)
{
	// SETUP
	setup_gpio();
	setup_spi();
	setup_uart();
	setup_motors();
	
	// Enable timer 3 to track motor active time
	// No prescaling
	TCCR3B = (1<<CS30);
	// Overflow interrupt enabled
	TIMSK3 = (1<<TOIE3);
	
	// Current and previous ADC readings, used to detect movement
	adc_readings_t current_readings;
	adc_readings_t old_readings;
	memset(&current_readings, 0, sizeof(adc_readings_t));
	memset(&old_readings, 0, sizeof(adc_readings_t));
	
	bool exercise_started = false;
	uint8_t motor_speed = 100;
	
	potentiometer pot_index = POT_THUMB_1;
	
	char recvbuf[64] = {0};
		
	// Used to prevent triggering the motors until 255 iterations of the main loop have happened, while the filters stabilize.
	uint8_t stabilize_delay = 255;
	
	sei();
	set_motor_enable(1);
	// LOOP
	while (1)
	{
		// Check for motor faults
		for (size_t i = 0; i < MOTOR_COUNT; i++)
		{
			if (motor_faulted[i])
			{
				exercise_started = false;
				bt_send_motor_warning(i);
			}
		}
		
		// Check for incoming commands
		// N.B. This should normally use the BT UART, but we are using an external module on the debug UART for the final demo because of timing issues.
		debug_recv(recvbuf, 64);
		if (recvbuf[0] == 0x85 && !exercise_started)
		{
			// Set resistance, only while exercise is stopped.
			// Higher resistance value => lower motor speed (smaller value set to 8 bit output compare register)
			switch (recvbuf[1])
			{
				case 1:
					motor_speed = 200;
					break;
				case 2:
					motor_speed = 175;
					break;
				case 3:
					motor_speed = 150;
					break;
				case 4:
					motor_speed = 125;
					break;
				case 5:
					motor_speed = 100;
					break;
				default:
					break;
			}
		}
		else if (recvbuf[0] == 0x01)
		{
			// Start exercise
			exercise_started = true;
			//set_motor_enable(1);
		}
		else if (recvbuf[0] == 0x82)
		{
			// Stop exercise
			exercise_started = false;
			//set_motor_enable(0);
		}
		
		// Read all pots and motors
		memcpy(&old_readings, &current_readings, sizeof(adc_readings_t));
		for (potentiometer i = POT_THUMB_1; i <= POT_PINKY_3; i++)
		{
			read_pot(i, &current_readings);
		}
		for (motor i = MOTOR_PINKY; i <= MOTOR_THUMB; i++)
		{
			read_motor(i, &current_readings);
		}

		// Wait for all the filters to stabilize before doing anything else
		if (stabilize_delay > 0)
		{
			stabilize_delay--;
			continue;
		}
		
		// Only send two readings per iteration to not overflow the send buffer
		bt_send_reading(pot_index, current_readings.potentiometers[pot_index] >> POT_FILTER_SHIFT);
		bt_send_reading(pot_index+1, current_readings.potentiometers[pot_index+1] >> POT_FILTER_SHIFT);
		pot_index += 2;
		if (pot_index > POT_PINKY_3)
		{
			pot_index = POT_THUMB_1;
		}
		
		int8_t flexion[MOTOR_COUNT];
		flexion[MOTOR_PINKY] = check_finger_flexion(&current_readings, &old_readings, POT_PINKY_1, POT_PINKY_2, POT_PINKY_3);
		flexion[MOTOR_RING] = check_finger_flexion(&current_readings, &old_readings, POT_RING_1, POT_RING_2, POT_RING_3);
		flexion[MOTOR_MIDDLE] = check_finger_flexion(&current_readings, &old_readings, POT_MIDDLE_1, POT_MIDDLE_2, POT_MIDDLE_3);
		flexion[MOTOR_INDEX] = check_finger_flexion(&current_readings, &old_readings, POT_INDEX_1, POT_INDEX_2, POT_INDEX_3);
		flexion[MOTOR_THUMB] = check_finger_flexion(&current_readings, &old_readings, POT_THUMB_1, POT_THUMB_2, POT_THUMB_2);
		
		for (motor i = MOTOR_PINKY; i <= MOTOR_THUMB; i++)
		{
			if (motor_cycles_remaining[i] > 0)
			{
				continue;
			}
			
			if (flexion[i] > 0)
			{
				set_motor_phase(i, DIRECTION_FORWARD);
				set_motor_speed(i, motor_speed);
				motor_cycles_remaining[i] = TC3_OVF_HALF_SECOND;
			}
			else if (flexion[i] < 0)
			{
				set_motor_phase(i, DIRECTION_BACKWARD);
				set_motor_speed(i, motor_speed);
				motor_cycles_remaining[i] = TC3_OVF_HALF_SECOND;
			}
			else
			{
				set_motor_speed(i, 0);
			}
		}
		
		_delay_ms(10);
	}
}

/*
// DEBUG TEST
int main(void)
{
	setup_gpio();
	setup_spi();
	setup_uart();
	setup_motors();
	
	char sendbuf[50] = {0};
	char recvbuf[50] = {0};
	
	sei();
	while (1)
	{
		// Write a bunch of data
		for (int i = 0; i < 10; i++)
		{
			for (int j = 10; j > 0; j--)
			{
				int sum = i + j;
				int diff = i - j;
				snprintf(sendbuf, 50, "%d + %d = %d; %d - %d = %d\n", i, j, sum, i, j, diff);
				debug_send(sendbuf);
				
				// Busy wait, try reducing the limit to see how fast the data is pumped out of the debug send buffer
				_delay_ms(100);
			}
		}
		
		// Echo back anything received
		size_t recv_cnt = debug_recv(recvbuf, 49);
		if (recv_cnt)
		{
			debug_send(recvbuf);
		}
	}
}
*/
/*
// BT TEST
int main(void)
{
	setup_gpio();
	setup_spi();
	setup_uart();
	setup_motors();
	
	char sendbuf[50] = {0};
	//char recvbuf[50] = {0};
	
	sei();
	while (1)
	{
		//char test[2] = {0b01010101, 0};
		strncpy(sendbuf, "ADD\n", 9);
		debug_send(sendbuf);
		//debug_send(sendbuf);
		
		//// Echo back anything received
		//size_t recv_cnt = bt_recv(recvbuf, 49);
		//if (recv_cnt)
		//{
			//bt_send(recvbuf);
			//debug_send(recvbuf);
		//}
		
		_delay_ms(1000);
	}
}
*/
/*
// SPI TEST
int main(void)
{
	// SETUP
	setup_gpio();
	setup_spi();
	setup_uart();
	setup_motors();
	
	adc_readings_t current_readings;
	adc_readings_t old_readings;
	
	memset(&current_readings, 0, sizeof(adc_readings_t));
	memset(&old_readings, 0, sizeof(adc_readings_t));
	
	char sendbuf[50] = {0};
	char recvbuf[50] = {0};
		
	uint8_t index = 0;
	
	sei();
	// LOOP
	while (1)
	{
		size_t bytes_read = debug_recv(recvbuf, 49);
		if (bytes_read > 0)
		{
			int conv = atoi(recvbuf);
			if (conv >= 0 && conv <= 13)
			{
				index = (uint8_t)conv;
				snprintf(sendbuf, 49, "Set index to %d\n", index);
				debug_send(sendbuf);
			}
			else
			{
				strncpy(sendbuf, "Index malformed or out of range\n", 49);
				debug_send(sendbuf);
			}
		}
		
		// Save old reading
		old_readings.potentiometers[index] = current_readings.potentiometers[index];
		// Get new reading
		read_pot(index, &current_readings);
		// Print debug message
		snprintf(sendbuf, 49, "Pot %d read %d (prev %d)\n", index, current_readings.potentiometers[index] >> POT_FILTER_SHIFT, old_readings.potentiometers[index] >> POT_FILTER_SHIFT);
		debug_send(sendbuf);
		
		_delay_ms(1000);
	}
}
*/

/*
// MOTOR TEST
int main(void)
{
	// SETUP
	setup_gpio();
	setup_spi();
	setup_uart();
	setup_motors();
	
	adc_readings_t current_readings;
	adc_readings_t old_readings;
	
	memset(&current_readings, 0, sizeof(adc_readings_t));
	memset(&old_readings, 0, sizeof(adc_readings_t));
	
	char sendbuf[64] = {0};
	char recvbuf[50] = {0};
	
	uint8_t index = 0;
	motor_direction direction = DIRECTION_FORWARD;
	
	sei();
	set_motor_enable(1);
	// LOOP
	while (1)
	{
		size_t bytes_read = debug_recv(recvbuf, 49);
		if (bytes_read > 0)
		{
			int conv = atoi(recvbuf);
			if (conv >= 0 && conv <= 4)
			{
				set_motor_speed(index, 0);
				index = (uint8_t)conv;
				snprintf(sendbuf, 49, "Set index to %d", index);
				debug_send(sendbuf);
			}
			else
			{
				strncpy(sendbuf, "Index malformed or out of range", 49);
				debug_send(sendbuf);
			}
		}
		
		set_motor_phase(index, direction);
		for (int spd = 0; spd < 200; spd += 5)
		{
			set_motor_speed(index, spd);
			_delay_ms(250);
			// Save old reading
			old_readings.motors[index] = current_readings.motors[index];
			// Get new reading
			read_motor(index, &current_readings);
			// Print debug message
			snprintf(sendbuf, 64, "Motor %u read %u (prev %u). Dir %d\n", index, current_readings.motors[index], old_readings.motors[index], direction);
			debug_send(sendbuf);
		}
		
		set_motor_speed(index, 0);
		if (direction == DIRECTION_BACKWARD)
		{
			direction = DIRECTION_FORWARD;
		}
		else
		{
			direction = DIRECTION_BACKWARD;
		}
			
		_delay_ms(10);
	}
}
*/

void setup_gpio(void)
{
	// PORTxn : If port x, pin n is input: 1 enables internal pull-up. If port x, pin n is output: sets value of port.
	// DDxn : Data Direction, Port x, Pin n. 1 = Output, 0 = Input
	PORTB = (1<<PORTB7) | (1<<PORTB6);
	DDRB = (1<<DDB0);
	
	PORTC = (1<<PORTC5) | (1<<PORTC3) | (1<<PORTC2);
	DDRC = (1<<DDC5) | (1<<DDC4) | (1<<DDC3) | (1<<DDC2);
	
	PORTD = (1<<PORTD4);
	DDRD = (1<<DDD7) | (1<<DDD2);
	
	PORTE = (1<<PORTE2) | (1<<PORTE1) | (1<<PORTE0);
	DDRE = (1<<DDE2);
}

// Check if a finger is flexing. Returns 1 if it's more flexed than the previous iteration, -1 if it's less flexed, 0 if unchanged.
int8_t check_finger_flexion(adc_readings_t *current, adc_readings_t *prev, potentiometer knuckle1, potentiometer knuckle2, potentiometer knuckle3)
{
	if (current->potentiometers[knuckle1] >> POT_FILTER_SHIFT < prev->potentiometers[knuckle1] >> POT_FILTER_SHIFT || 
		current->potentiometers[knuckle2] >> POT_FILTER_SHIFT < prev->potentiometers[knuckle2] >> POT_FILTER_SHIFT || 
		current->potentiometers[knuckle3] >> POT_FILTER_SHIFT < prev->potentiometers[knuckle3] >> POT_FILTER_SHIFT)
	{
		return 1;
	}
	else if (current->potentiometers[knuckle1] >> POT_FILTER_SHIFT > prev->potentiometers[knuckle1] >> POT_FILTER_SHIFT || 
			 current->potentiometers[knuckle2] >> POT_FILTER_SHIFT > prev->potentiometers[knuckle2] >> POT_FILTER_SHIFT || 
			 current->potentiometers[knuckle3] >> POT_FILTER_SHIFT > prev->potentiometers[knuckle3] >> POT_FILTER_SHIFT)
	{
		return -1;
	}
	return 0;
}

ISR(TIMER3_OVF_vect)
{
	for (motor i = MOTOR_PINKY; i <= MOTOR_THUMB; i++)
	{
		if (motor_cycles_remaining[i] > 0)
		{
			motor_cycles_remaining[i]--;
		}
	}
}

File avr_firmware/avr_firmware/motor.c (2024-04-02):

/*
 * motor.c
 *
 * Created: 2024-03-19 1:37:31 PM
 *  Author: Matthew Faigan
 */ 

#include "motor.h"

#include <avr/io.h>
#include <avr/interrupt.h>
#include <stdbool.h>

#include "uart.h"

// ISR will set this so we can handle notifying the application in the main loop
volatile bool motor_faulted[MOTOR_COUNT];

void setup_motors(void)
{
	// N.B. The different hardware counters have different capabilities and configuration methods.
	// Before you modify any of the setup code here, make sure you read the appropriate section in the datasheet.
	
	/* TC0 (thumb and index finger) */
	// Set PD5 and PD6 as outputs
	DDRD |= (1<<DDD6) | (1<<DDD5);
	// Set OC0A and OC0B to fast PWM, non-inverting
	TCCR0A = (1<<COM0A1) | (1<<COM0B1) | (1<<WGM01) | (1<<WGM00);
	// Set no prescaling
	TCCR0B = (1<<CS00);
	// Default both output compares to 0
	OCR0A = 0;
	OCR0B = 0;
	
	/* TC1 (middle and ring fingers) */
	// Set PB1 and PB2 as outputs
	DDRB |= (1<<DDB2) | (1<<DDB1);
	// Set fast PWM non-inverting with top value of 0x00FF, no prescaling
	TCCR1A = (1<<COM1A1) | (1<<COM1B1) | (1<<WGM10);
	TCCR1B = (1<<WGM12) | (1<<CS10);
	// Default output compares to 0
	OCR1A = 0;
	OCR1B = 0;
	
	/* TC2 (pinky) */
	// Set PD3 as output
	DDRD |= (1<<DDD3);
	// Leave OC2A unused, set OC2B to fast PWM non-inverting
	TCCR2A = (1<<COM2B1) | (1<<WGM21) | (1<<WGM20);
	// No prescaling
	TCCR2B = (1<<CS20);
	// Default output compare to 0
	OCR2B = 0;
	
	// Initialize pin change interrupts for motor fault
	PCICR = (1<<PCIE3) | (1<<PCIE2) | (1<<PCIE0);
	PCMSK3 = (1<<PCINT25) | (1<<PCINT24);
	PCMSK2 = (1<<PCINT20);
	PCMSK0 = (1<<PCINT7) | (1<<PCINT6);
}

int set_motor_speed(motor motor_num, uint8_t duty)
{
	switch (motor_num)
	{
		case MOTOR_THUMB:
			OCR0A = duty;
			break;
		case MOTOR_INDEX:
			OCR0B = duty;
			break;
		case MOTOR_MIDDLE:
			OCR1A = duty;
			break;
		case MOTOR_RING:
			OCR1B = duty;
			break;
		case MOTOR_PINKY:
			OCR2B = duty;
			break;
		default:
			return 1;
	}
	return 0;
}

// This is ugly but I don't know a better way to do it!!
int set_motor_phase(motor motor_num, motor_direction direction)
{
	// Get the current value of the register containing the bit to change
	uint8_t current_value;
	uint8_t mask;
	switch (motor_num)
	{
		case MOTOR_THUMB:
			current_value = PORTD;
			mask = 1<<PORTD2;
			break;
		case MOTOR_INDEX:
		case MOTOR_MIDDLE:
			current_value = PORTC;
			mask = 1<<PORTC4;
			break;
		case MOTOR_RING:
		case MOTOR_PINKY:
			current_value = PORTD;
			mask = 1<<PORTD7;
			break;
		default:
			return 1;
	}
	
	// Motor has forward direction if PH = 1, backwards if PH = 0
	uint8_t new_value;
	switch (direction)
	{
		case DIRECTION_FORWARD:
			new_value = current_value | mask;
			break;
		case DIRECTION_BACKWARD:
			new_value = current_value & ~mask;
			break;
		default:
			return 1;
	}
	
	// Set the new value
	switch (motor_num)
	{
		case MOTOR_THUMB:
		case MOTOR_RING:
		case MOTOR_PINKY:
			PORTD = new_value;
			break;
		case MOTOR_INDEX:
		case MOTOR_MIDDLE:
			PORTC = new_value;
			break;
		default:
			return 1;
	}
	return 0;
}

int set_motor_enable(uint8_t state)
{
	if (state != 0 && state != 1)
	{
		return 1;
	}
	
	uint8_t mask = 1<<PORTB0;
	uint8_t new_bit = state<<PORTB0;
	uint8_t current = PORTB;
	
	PORTB = (current & ~mask) | (new_bit & mask);
	
	return 0;
}

ISR(PCINT3_vect)
{
	if (!(PORTE & (1<<PORTE0)))
	{
		set_motor_enable(0);
		motor_faulted[MOTOR_MIDDLE] = true;
	}
	if (!(PORTE & (1<<PORTE1)))
	{
		set_motor_enable(0);
		motor_faulted[MOTOR_RING] = true;
	}
}

ISR(PCINT2_vect)
{
	if (!(PORTD & (1<<PORTD4)))
	{
		set_motor_enable(0);
		motor_faulted[MOTOR_PINKY] = true;
	}
}

ISR(PCINT0_vect)
{
	if (!(PORTB & (1<<PORTB6)))
	{
		set_motor_enable(0);
		motor_faulted[MOTOR_THUMB] = true;
	}
	if (!(PORTB & (1<<PORTB7)))
	{
		set_motor_enable(0);
		motor_faulted[MOTOR_INDEX] = true;
	}
}

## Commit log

2023-11-04 Create KiCad project
    [glove_pcb.kicad_pcb, glove_pcb.kicad_sch]
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2023-11-15 Add switching regulator
    [flex.kicad_sch, glove_pcb.kicad_sch, motor.kicad_sch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]
2023-11-15 More work on motor driver connection
    [flex.kicad_sch, glove_pcb.kicad_sch, motor.kicad_sch]
2023-11-16 Add new dc motor driver
    [motor.kicad_sch]
2023-11-21 Replace offboard components with connectors, add uC, add example mux, fix motor wiring
    [controller.kicad_sch, flex.kicad_sch, glove_pcb.kicad_sch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]
2023-11-21 Finish controller pin assignments
    [controller.kicad_sch, power.kicad_sch]
2023-11-23 Minor changes from meeting with dmitry
    [controller.kicad_sch, flex.kicad_sch, glove_pcb.kicad_sch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]
2023-11-23 Yet more improvements to the schematic
    [controller.kicad_sch, flex.kicad_sch, motor.kicad_sch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]
2023-11-24 Add logic level shifter to controller schematic
    [controller.kicad_sch]
2023-11-24 Finish schematic
    [bluetooth.kicad_sch, controller.kicad_sch, glove_pcb.kicad_sch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]
2023-11-24 Add titles to pages and reannotate
    [bluetooth.kicad_sch, controller.kicad_sch, flex.kicad_sch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]
2023-11-25 Finalize schematic for real this time
    [bluetooth.kicad_sch, controller.kicad_sch, flex.kicad_sch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]
2024-01-09 Added Footprints
    I Added footprints for every components in PCB
    [bluetooth.kicad_sch, controller.kicad_sch, flex.kicad_sch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]
2024-01-11 UC pin assignment documentation
2024-01-18 Create PCB constraints and add footprints from schematic
    [glove_pcb.kicad_pcb]
2024-01-18 Change barrel jack footprint and minor placing work
    [glove_pcb.kicad_pcb, power.kicad_sch]
2024-01-19 More partial placement of footprints
    [glove_pcb.kicad_pcb, power.kicad_sch]
2024-01-19 Group up footprints with same location, not organized yet
    [glove_pcb.kicad_pcb]
2024-01-23 Made most of changes from meeting
    [bluetooth.kicad_sch, controller.kicad_sch, flex.kicad_sch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]
2024-01-24 Finish changes according to feedback
    [bluetooth.kicad_sch, controller.kicad_sch, flex.kicad_sch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]
2024-01-25 Finish schematic updates
    [bluetooth.kicad_sch, controller.kicad_sch, flex.kicad_sch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]
2024-01-29 More updates to the schematic based on Dmitry's feedback
    [bluetooth.kicad_sch, controller.kicad_sch, flex.kicad_sch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]
2024-02-13 Change isp pin symbol
    [bluetooth.kicad_sch, controller.kicad_sch, flex.kicad_sch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]
2024-02-14 Assign footprints and import all parts into pcb editor
    [bluetooth.kicad_sch, controller.kicad_sch, glove_pcb.kicad_pcb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]
2024-02-15 Minor changes
    [glove_pcb.kicad_pcb]
2024-02-15 Coarse placement of components
    [glove_pcb.kicad_pcb]
2024-02-15 More tentative placing work
    [glove_pcb.kicad_pcb]
2024-02-16 More placing
    [controller.kicad_sch, glove_pcb.kicad_pcb]
2024-02-16 Changes before & during meeting
    [flex.kicad_sch, glove_pcb.kicad_pcb]
2024-02-23 Re-placing with new outline
    [controller.kicad_sch, glove_pcb.kicad_pcb, motor.kicad_sch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]
2024-02-23 Reworking placing
    [bluetooth.kicad_sch, controller.kicad_sch, flex.kicad_sch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]
2024-02-23 Re-placing motor drivers & related footprints
    [glove_pcb.kicad_pcb]
2024-02-24 Added Bluetooth Module Copper
    [glove_pcb.kicad_pcb]
2024-02-24 Finish re-placing + draw copper zones
    [flex.kicad_sch, glove_pcb.kicad_pcb]
2024-02-24 Adjust placing based on size conflicts
    [flex.kicad_sch, glove_pcb.kicad_pcb]
2024-02-24 Starting routing
    [glove_pcb.kicad_pcb]
2024-02-24 Minor footprint and routing fixes
    [glove_pcb.kicad_pcb]
2024-02-24 Did the Routing for PCB
    [controller.kicad_sch, glove_pcb.kicad_pcb]
2024-02-24 Increasing via sizes and minor routing changes
    [glove_pcb.kicad_pcb]
2024-02-24 Modified the Vias
    [glove_pcb.kicad_pcb]
2024-02-25 Changes from before submission saturday morning
    [glove_pcb.kicad_pcb]
2024-02-26 Changes before/after meeting w Dimitry
    [controller.kicad_sch, flex.kicad_sch, glove_pcb.kicad_pcb]
2024-02-26 Fixed some of the clearance as well as some routing issues
    [glove_pcb.kicad_pcb]
2024-02-26 More routing re-work and cleanup
    [glove_pcb.kicad_pcb]
2024-02-26 Improving routing to voltage regulators
    [glove_pcb.kicad_pcb]
2024-02-27 Clearance should be fixed as well as tracks for motors were increased
    [glove_pcb.kicad_pcb]
2024-02-27 Silkscreen cleanup and final fixes
    [glove_pcb.kicad_pcb]
2024-02-27 3V3 RXD track clearance
    [glove_pcb.kicad_pcb]
2024-02-27 Minor changes in the morning before meeting
    [glove_pcb.kicad_pcb]
2024-02-27 More intermediate changes
    [bluetooth.kicad_sch, controller.kicad_sch, glove_pcb.kicad_pcb]
2024-02-27 Important changes from meeting
    [glove_pcb.kicad_pcb]
2024-02-27 More improvements and routing fixes
    [bluetooth.kicad_sch, controller.kicad_sch, flex.kicad_sch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]
2024-02-27 Routing cleanup and aesthetics
    [glove_pcb.kicad_pcb]
2024-02-27 Slight Adjustments for routing
    [glove_pcb.kicad_pcb]
2024-02-27 Final touches for today's feedback
    [glove_pcb.kicad_pcb]
2024-03-10 Minor pin assignment update
2024-03-13 Partial work on SPI library
2024-03-15 Finish implementation of ADC readings
2024-03-16 Create circular buffer for uart usage
2024-03-17 Partial work on debug uart
2024-03-19 Finish UART for serial debugging, not tested yet
2024-03-20 Partial work on motor control code
2024-03-20 Finish motor functions aside from fault interrupts
2024-03-20 Update PCB files to Kicad 8.0
    [bluetooth.kicad_sch, controller.kicad_sch, flex.kicad_sch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]
2024-03-24 Improve SPI test for tomorrow, add filtering
2024-03-27 Changes while debugging SPI and motors
2024-03-31 SPI cleanup and filtering, also enhance circular buffer
2024-04-01 Working on motor fault detection and sending of readings
2024-04-02 Final attempt at motor control from firmware
